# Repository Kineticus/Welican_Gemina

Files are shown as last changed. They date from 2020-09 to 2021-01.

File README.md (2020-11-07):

# Welican Gemina

A custom ESP32 module that controls WS2811 lights, a 1.3" OLED I2C, a MSGEQ7 Microphone board, and 2 encoders.

```
Your README file is normally the first entry point to your code. It should tell people why they should use your module, how they can install it, and how they can use it. Standardizing how you write your README makes creating and maintaining your READMEs easier. Great documentation takes work!
```

This repository contains:

1. [Board Design](BOARD_DESIGN.md) to show the custom ESP32 boarddesigned for this project.

## TODOs

- WIFI Manager
- ~~Saving Favorites~~
  - ~~Favorites Menu~~
- ~~Settings~~
  - ~~Set Led Count~~
  - ~~Show IP~~
  - Timeout (short, medium, long, extra long, never)
    - Show Weather/Clock
    - Turn off
  - ~~Clock Types~~
  - ~~Random Mode Speed (short, medium, long, extra long, never)~~
  - ~~Color Order (RGB, GRB, etc)~~
  - ~~Factory Reset (reset EPROM values to default, favorites, highscores)~~
- ~~Random Mode at beginning of categories~~
- ~~Fade between patterns (to prevent quick spins on pattern knob)~~
- Audio Input morphs Music Visualizer category lights
- More visualizers (VZ)
  - Random VZ for each category (at the beginning of category)
  - Differnt types of random (at the end of category)
- ~~Weather status~~
  - ~~By Zipcode~~
  - VZ based on weather
- ~~Get Time~~
  - ~~Show time in top menu~~

## Table of Contents

- [Background](#background)
- [Install](#install)
  - [Install Arduino Libraries](#install-arduino-libraries)
  - [VS Code & C++](#vs-code-&-c++)
- [Related Documents](#related-documents)
- [Maintainers](#maintainers)
- [Contributing](#contributing)
- [Helpful Links](#helpful-links)
- [FastLed Examples](#fastled-examples)
- [License](#license)

## Background
```
  // TODO add stuff
```
## Install

This project requires the [Arduino IDE](https://www.arduino.cc/en/Main/Software).

1. Install [Arduino IDE](https://www.arduino.cc/en/Main/Software).
2. In the Ardunio IDE, go to `File > Preferences` (CTRL + Comma).
    
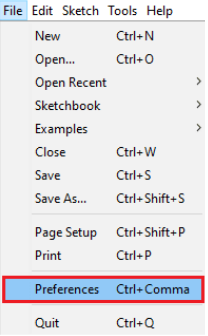
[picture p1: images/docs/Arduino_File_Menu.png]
Arudino File Menu
    

3. Enter `https://dl.espressif.com/dl/package_esp32_index.json` into the “Additional Board Manager URLs” field as shown in the figure below. Then, click the “OK” button.

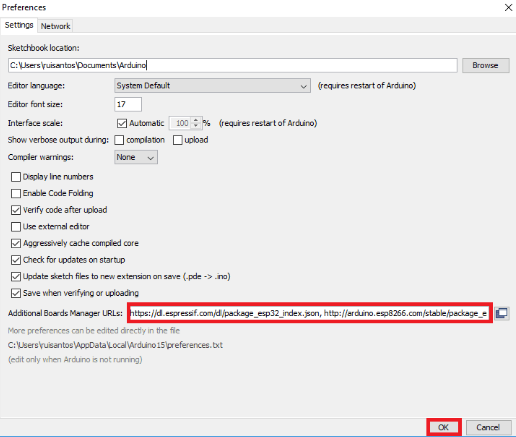
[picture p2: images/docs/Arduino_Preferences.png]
Arudino Preferneces
    

  - Note: if you already have the ESP8266 boards URL, you can separate the URLs with a comma as follows:
  `https://dl.espressif.com/dl/package_esp32_index.json, http://arduino.esp8266.com/stable/package_esp8266com_index.json`

4. Open the Boards Manager. Go to `Tools > Board > Boards Manager`

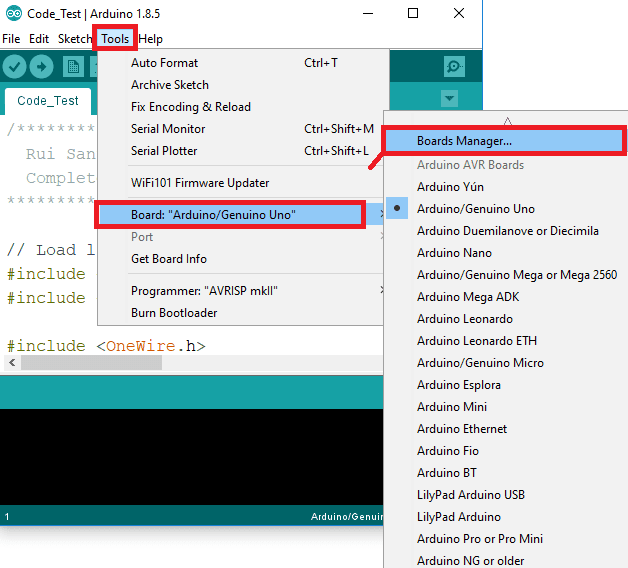
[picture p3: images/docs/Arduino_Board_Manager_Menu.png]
Arudino Board Manager Menu
    

5. Search for ESP32 and press install button for the “ESP32 by Espressif Systems“

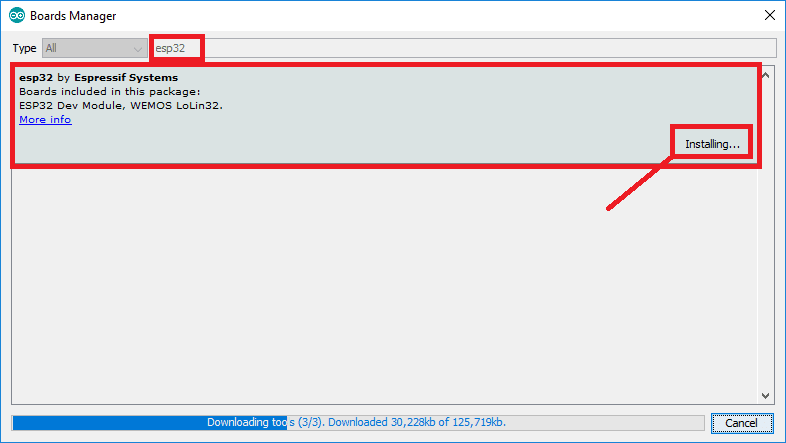
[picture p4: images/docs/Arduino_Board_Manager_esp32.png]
Arudino Board Manager Menu
    

    - That’s it! Make sure to change the Board under the Tools menu to “ESP32 Dev Module”

### Install Arduino Libraries

6. Libraries `Tools > Manage Libraries` (Location is User Directory\Documents\Arduino\libraries)
  - [ESP32Encoder](https://github.com/madhephaestus/ESP32Encoder)
  - [FastLED](https://github.com/FastLED/FastLED/wiki)
    - [FastLED Samguyer Fork](https://github.com/samguyer/FastLED) *Optional
  - [arduinoFFT](https://github.com/kosme/arduinoFFT)
  - [U8g2](https://github.com/olikraus/u8g2/wiki/u8g2reference)
  - [ESPAsyncWebServer](https://github.com/me-no-dev/ESPAsyncWebServer) *Must be installed manually
  - [ASyncTCP](https://github.com/me-no-dev/AsyncTCP) *Must be installed manually
  - [ESP32 File System Tool](https://github.com/me-no-dev/arduino-esp32fs-plugin) *Must be installed manually by copying to Tools folder!! Read instructions carefully.
  
### Create Wifi Credentials file

7. Create a file called `Secrets.h` in the main folder.
That file should include the following:
```
#define WIFI_SSID "your-wifi-ssid-goes-here"
#define WIFI_PASSWORD "your-wifi-password-goes-here"
#define OPEN_WEATHER_API_KEY "your-open-weather-api-key"
```

You will need to replace the strings with your WIFI SSID and PASSWORD

### VS Code & C++
  - [.vscode/c_app_properties.json](https://code.visualstudio.com/docs/cpp/customize-default-settings-cpp)
  - [Arduino Extension](https://marketplace.visualstudio.com/items?itemName=vsciot-vscode.vscode-arduino)
  - [C++ Extension](https://marketplace.visualstudio.com/items?itemName=ms-vscode.cpptools)
  - [GitLens Extension](https://marketplace.visualstudio.com/items?itemName=eamodio.gitlens)

## Related Documents

- [Welican Project Doc](https://docs.google.com/document/d/e/2PACX-1vS1qt4seWkiZLkJHX4LD_V3VYEt1su2fU610a7UOJ1a_LkRgppqzjMMRaHVzRj_jQmDRsJIRdGVeDGK/pub) - The brain-dump file created by @Kinectus
- [BOM](https://docs.google.com/spreadsheets/d/1Lj1XwBXrHm5YGtD2jA4sHXP_yh42TAKp-GVNhS_lHCg/edit?usp=sharing) - Price / Cost spreadsheet created by @Kinectus

## Maintainers

  - [@Kinectus](https://github.com/Kineticus/)

  - [@MaylorTaylor](https://github.com/MaylorTaylor/)

## Contributing

Feel free to dive in! [Open an issue](https://github.com/Kineticus/Welican_Gemina/issues/new) or submit PRs.

Standard Readme follows the [Contributor Covenant](http://contributor-covenant.org/version/1/3/0/) Code of Conduct.

## Helpful Links

  - [C++ Classes](https://www.stroustrup.com/C++11FAQ.html#member-init)
  - [Custom XBM Image Convert](https://www.online-utility.org/image/convert/to/XBM)
  - [Arduino C++ & VSCode](https://learn.sparkfun.com/tutorials/efficient-arduino-programming-with-arduino-cli-and-visual-studio-code/all)
  - [Arduino Intellisense VSCode](https://cuneyt.aliustaoglu.biz/en/enabling-arduino-intellisense-with-visual-studio-code/)
  - [Experimental FastLED RGBSet](https://github.com/FastLED/FastLED/wiki/RGBSet-Reference)
  - [Refactoring out DELAY](https://forum.arduino.cc/index.php?topic=537644.0)
  - [UG82 Screen Library](https://github.com/olikraus/u8g2)
  - [Strings for CPP](https://cpp4arduino.com/2018/11/21/eight-tips-to-use-the-string-class-efficiently.html)

## FastLED Examples

  - [Demos](https://github.com/atuline/FastLED-Demos)
  - [Demos 2](https://github.com/marmilicious/FastLED_examples)
  - [Demos 3](https://www.tweaking4all.com/hardware/arduino/adruino-led-strip-effects/)
  - [Flagpole](https://github.com/chemdoc77/CD77_FastLED_Projects/tree/master/CD77_Flagpole_Project)
  - [Chase Demo](https://github.com/chemdoc77/CD77_FastLED/tree/master/CD77_Chase_Demo)

## License

[MIT License](/LICENSE.md) © Welican LLC

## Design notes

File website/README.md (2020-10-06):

# Welican Gemina Website

## Installing

  1. Make sure you download [Node.JS](https://nodejs.org/en/download/) (so you can use `npm` commands)
  2. Make sure your terminal is in the `/website` folder.
  3. Run `npm install` to install all the dependencies in the `package.json` file.

## Build Process
  
  1. Run `npm run build`
    - This will use the `webpack.config.js` file to grab all files in `/images`, all `./styles/**.scss` files, and all the `./src/**.js` files and put the minified files into `./data/` folder.
  2. Go To ARUDINO SOFTWARE, then TOOLS > `ESP32 Data Sketch Upload`. Click this and do the "upload" to add the files to the ESP32 device.

## Developing

  1. Run `npm run start:dev`, this will launch a local server and host the files in the `./src` folder at `http://localhost:8080/`

## Helpful Places

  - [CSS from Mini.css](https://minicss.org/docs#getting-started)
  - [Images using ESP32](https://randomnerdtutorials.com/display-images-esp32-esp8266-web-server/)

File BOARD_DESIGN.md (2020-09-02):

# ESP32 Board Design

## Table of Contents

- [ESP Pictures](#esp-pictures)
- [Technical Information about ESP32](#Technical-Information-about-ESP32)
- [Advanced Troubleshooting and Programming](#Advanced-Troubleshooting-and-Programming)
- [Encoder](#encoders)
- [Display](#display)
- [LED Signaling](#LED-Signaling)
- [Case / Enclosure](#case-/-enclosure)

## ESP Pictures

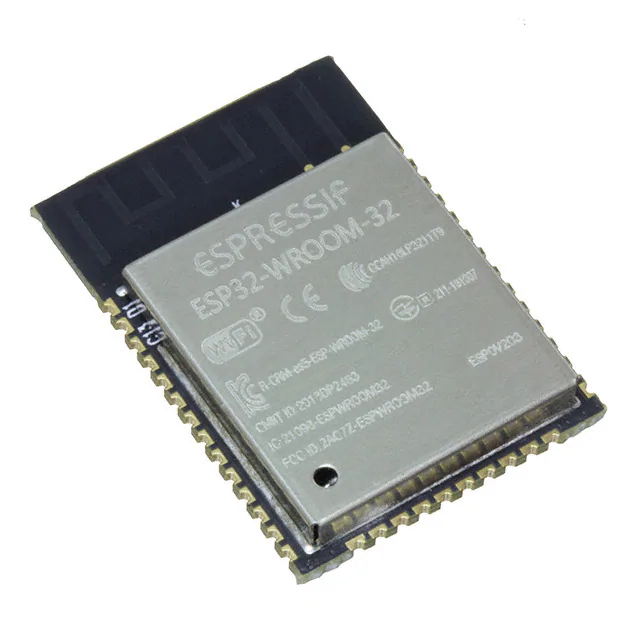
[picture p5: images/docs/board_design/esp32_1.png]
ESP32 1


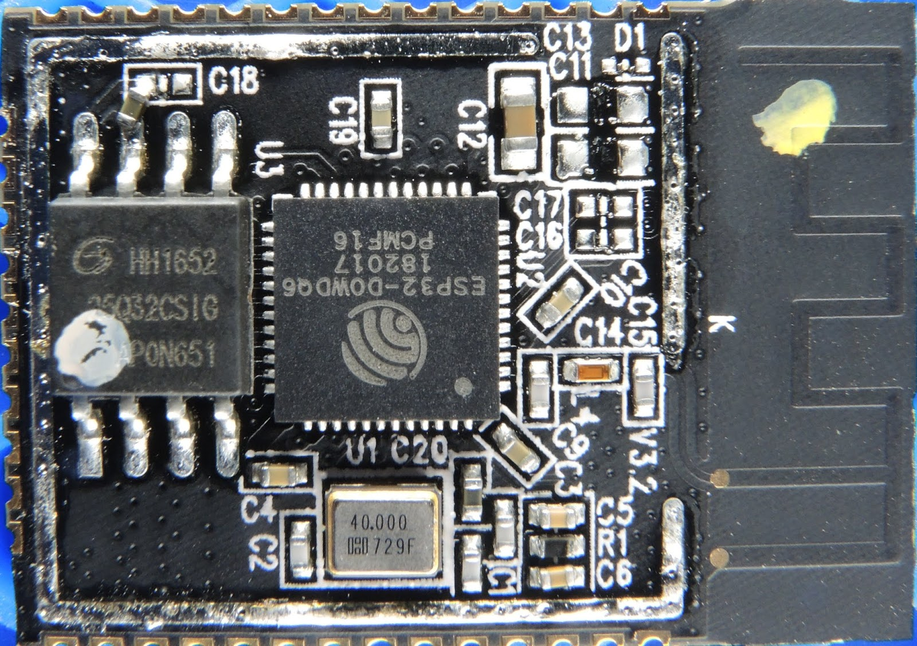
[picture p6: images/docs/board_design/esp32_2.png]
ESP32 2


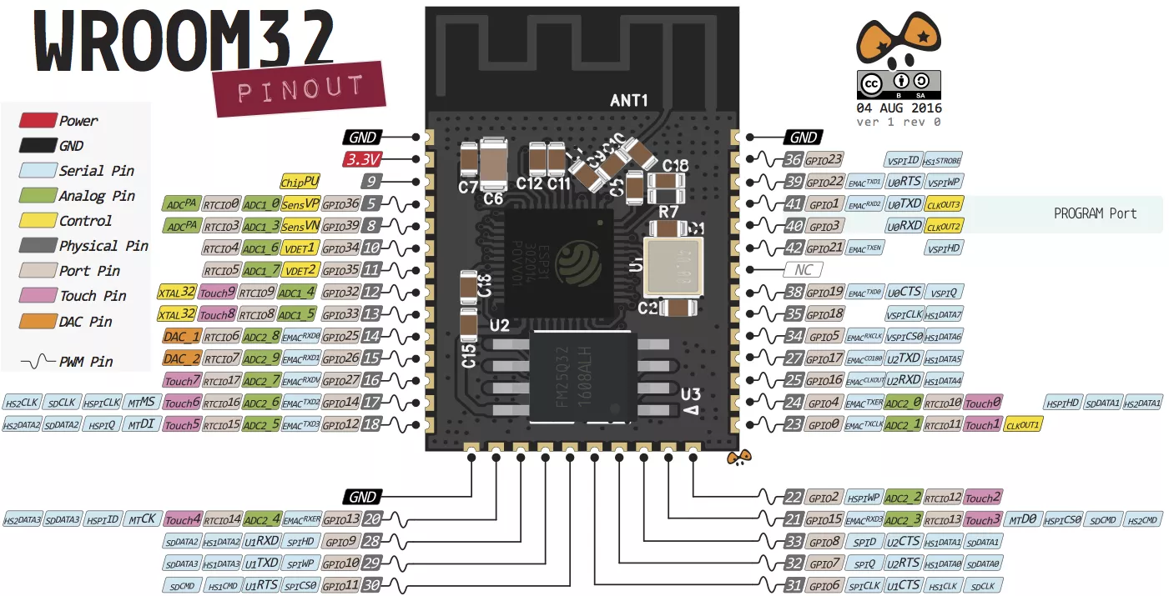
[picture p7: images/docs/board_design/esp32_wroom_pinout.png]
ESP32 Wroom PinOut


## Technical Information about ESP32

  - [Data Sheet](https://www.mouser.com/datasheet/2/891/esp32-wroom-32d_esp32-wroom-32u_datasheet_en-1365844.pdf)

  - [Strapping Pins and Boot Mode Selection](https://github.com/espressif/esptool/wiki/ESP32-Boot-Mode-Selection)

    - USB Serial Monitor - PuTTY on Serial Port at 115200 baud
      - This will report which boot mode is selected based on strapping Pins
  - [Multicore](https://randomnerdtutorials.com/esp32-dual-core-arduino-ide/)

  ## Advanced Troubleshooting and Programming       

  - [ESP Tool](https://github.com/espressif/esptool) (Requires Python)
    - Once Python is installed open an elevated command prompt and navigate to the extracted files
    - To get board information:
      - `py espefuse.py --port COM3 summary`
    - Flash Information:
      - `py esptool.py flash_id`
    - You’ll find you have missing packages. Use the structure below to install them
      - `python -m pip install pyserial`

## Encoders

  - [Encoder Library](https://www.pjrc.com/teensy/td_libs_Encoder.html)
    - This library is able to attach inputs to interrupt pins. This prevents constant polling.
  - Wiring / Pins

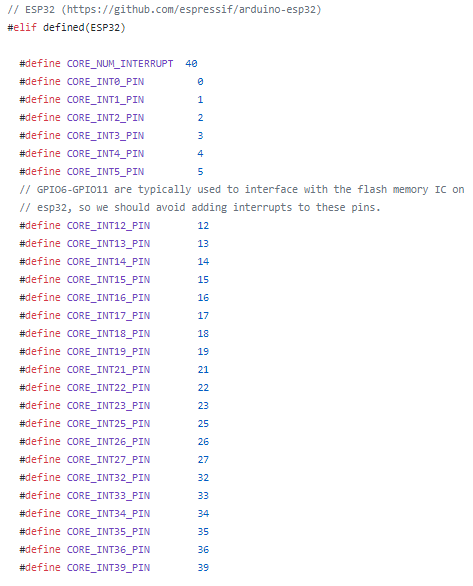
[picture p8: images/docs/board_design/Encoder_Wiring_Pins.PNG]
Encoder Wiring Pins
    

## Display

  - SSD1106 based OLED (128 x 64 pixels)

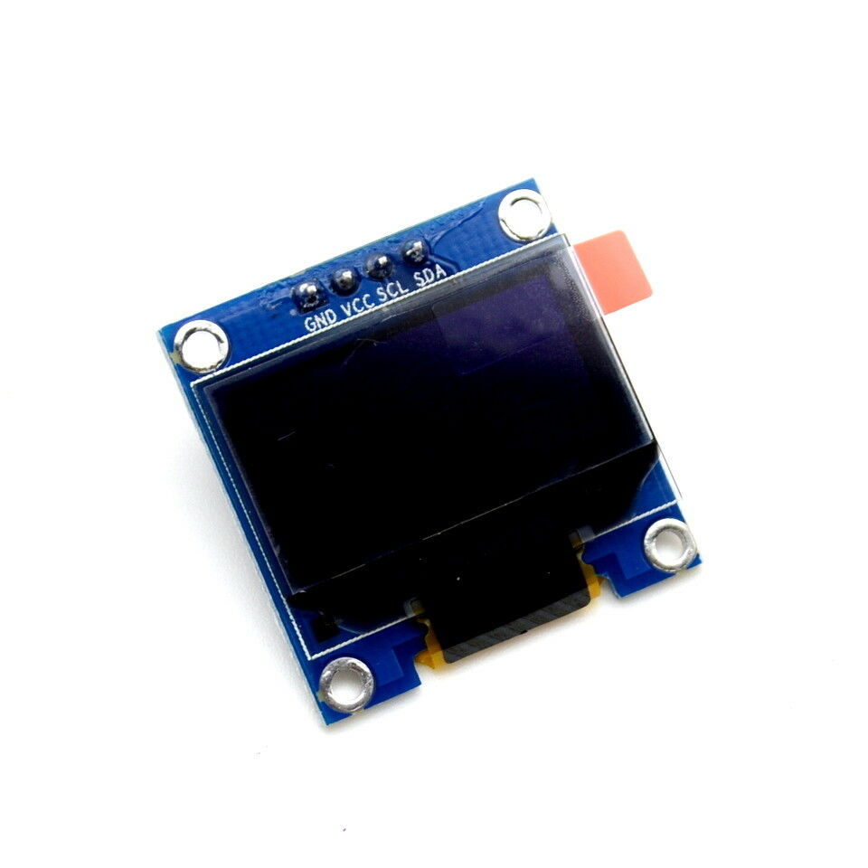
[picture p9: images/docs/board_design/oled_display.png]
OLED Display
    

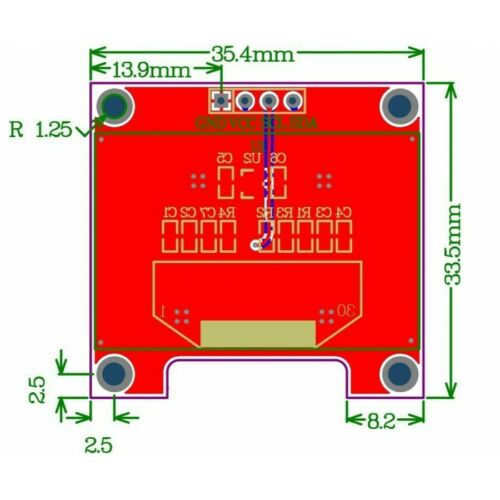
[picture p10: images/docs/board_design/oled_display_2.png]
OLED Display 2
    

    - Available in White or Blue
    - Library: [U8g2lib](https://github.com/olikraus/u8g2)
      - I2C address: 0x3C
      - #define OLED_RESET -1
    - Wiring / Pins
      - SCL   GPIO 22   (hardware I2C SCL)
      - SDA   GPIO 21   (hardware I2C SDA)

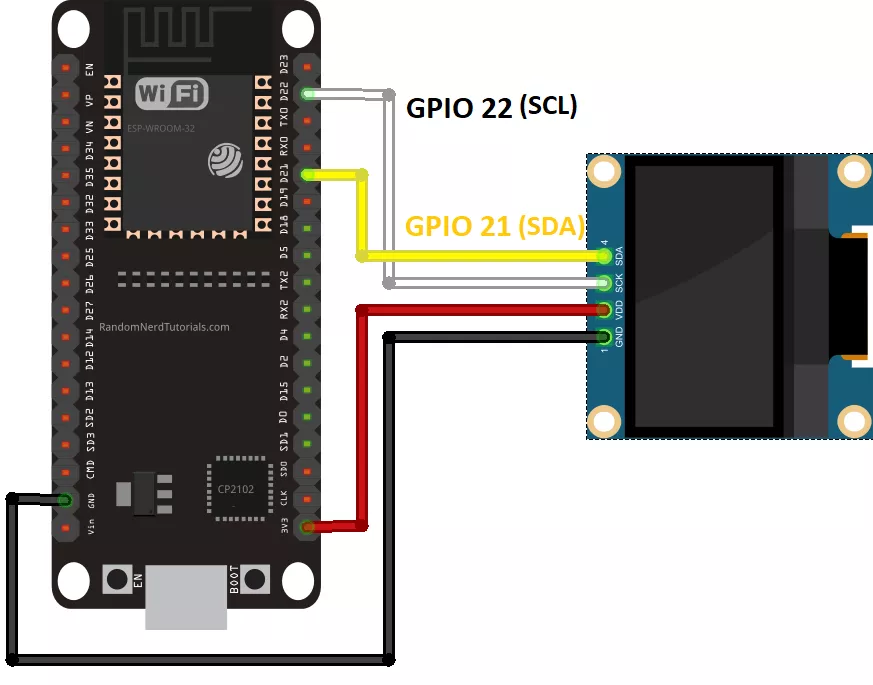
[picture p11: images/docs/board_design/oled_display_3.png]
OLED Display 3
    

    - Usage
      - [Custom Images](https://www.online-utility.org/image/convert/to/XBM)
      - [Custom Font](https://github.com/olikraus/u8g2/wiki/fntlistall)
      - [Custom Shapes / Drawing](https://github.com/olikraus/u8g2/wiki/u8g2reference)

## LED Signaling

  - [FastLED Library](https://github.com/FastLED/FastLED/)
    - [FastLED Wiki](https://github.com/FastLED/FastLED/wiki/Overview)
      - [Controlling LEDS](https://github.com/FastLED/FastLED/wiki/Controlling-leds)
      - [Pixel Reference](https://github.com/FastLED/FastLED/wiki/Pixel-reference)
      - [HSV Colors](https://github.com/FastLED/FastLED/wiki/FastLED-HSV-Colors)
      - [Gradient Color Palettes](https://github.com/FastLED/FastLED/wiki/Gradient-color-palettes)
    - Technical
      - [Clockless RMT ESP32](https://github.com/FastLED/FastLED/blob/master/platforms/esp/32/clockless_rmt_esp32.h)
      - [Temporal Dithering](https://github.com/FastLED/FastLED/wiki/FastLED-Temporal-Dithering)
      - [High Performance Math](https://github.com/FastLED/FastLED/wiki/High-performance-math)
      - [Experimental Hardware SPI](https://github.com/FastLED/FastLED/pull/1047)
  - Wiring / Pins for RMT Hardware Accelerated use on ESP32. Allows up to 8 unique strands.
    - [Fast Pin ESP32](https://github.com/FastLED/FastLED/blob/master/platforms/esp/32/fastpin_esp32.h)

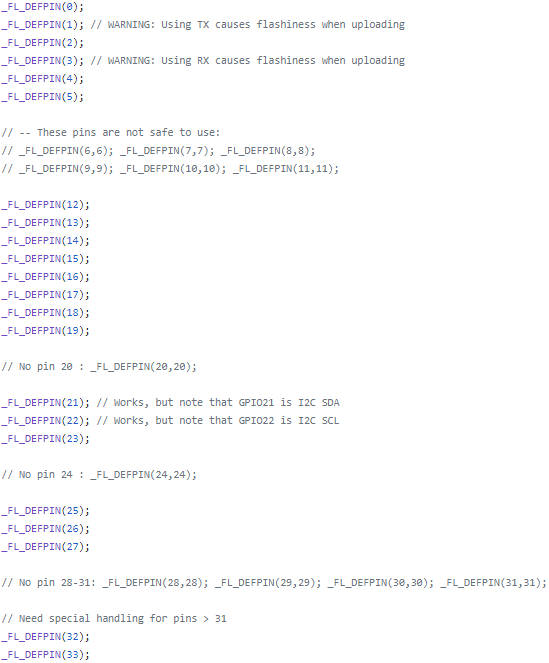
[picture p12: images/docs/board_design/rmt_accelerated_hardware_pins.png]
Wiring / Pins for RMT Hardware Accelerated use on ESP32
    

## Case / Enclosure

  - [ABS Plastic boxes with board standoffs](https://www.hammfg.com/electronics/small-case/plastic/1591xx)
  - [Polycarbonate Plastic boxes without board standoffs](https://www.hammfg.com/electronics/small-case/plastic/1591t)
  - [Sloping Console](https://www.hammfg.com/electronics/small-case/plastic/1599t)
  - [Anti-slip Feet 3M SJ5001](https://www.mouser.com/ProductDetail/3m/sj5001-blk/?qs=ItEYEd4DnG1l70qV%252buXsng%3D%3D)
  - [Stand-Offs / Screws for OLED/PCB]()
  - 3D Printed Custom Box
    - Sam will design and print.  Can utilize online printer shops for bulk manufacturing.

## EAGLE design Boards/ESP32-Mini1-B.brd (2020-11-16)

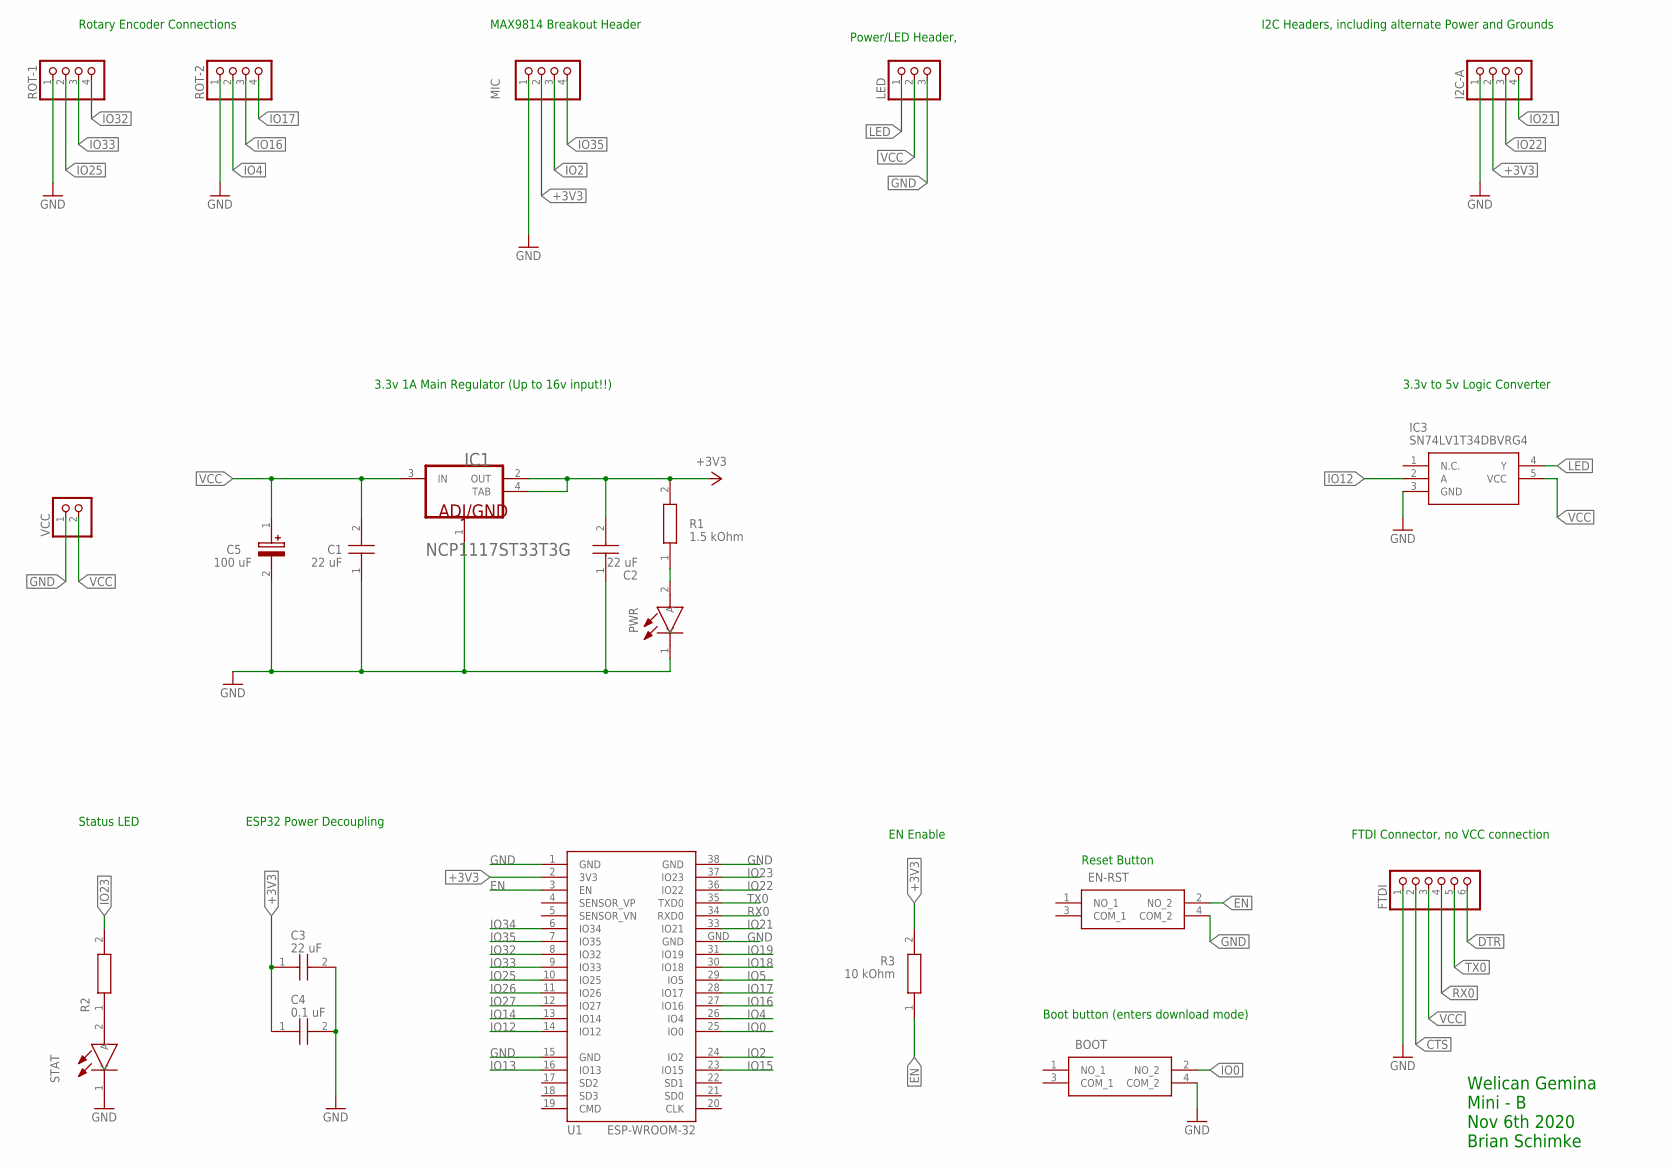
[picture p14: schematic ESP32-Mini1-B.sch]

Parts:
BOOT: PTS647SK70SMTR2LFS
C1, C2, C3: 22 uF; CAPC3216X180N
C4: 0.1 uF; CAPC3216X180N
C5: 100 uF; CAPAE660X770N
EN-RST: PTS647SK70SMTR2LFS
FTDI: PINHD-1X6; 1X06
I2C-A: PINHD-1X4; 1X04
IC1: ON_SEMICONDUCTOR_NCP1117ST33T3GON_SEMICONDUCTOR_N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; ON_SEMICONDUCTOR_NCP1117ST33T3G_0
IC3: SN74LV1T34DBVRG4; SOT95P280X145-5N
LED: PINHD-1X3; 1X03
MIC: PINHD-1X4; 1X04
PWR: 150120AS75000; LEDSC320X160X78-2N
R1: 1.5 kOhm; RESC3216X60N
R2: CRCW12061K00FKEB; RESC3216X60N
R3: 10 kOhm; RESC3216X60N
ROT-1, ROT-2: PINHD-1X4; 1X04
STAT: 150120AS75000; LEDSC320X160X78-2N
U1: ESP-WROOM-32
VCC: PINHD-1X2; 1X02

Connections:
+3V3: C2.2, C3.1, C4.1, I2C-A.2, IC1.2 (OUT), IC1.4 (TAB), MIC.2, R1.2, R3.2, U1.2 (3V3)
CTS: FTDI.2
DTR: FTDI.6
EN: EN-RST.2 (NO_2), R3.1, U1.3 (EN)
GND: BOOT.4 (COM_2), C1.1, C2.1, C3.2, C4.2, C5.2 (-), EN-RST.4 (COM_2), FTDI.1, I2C-A.1, IC1.1 (ADJ/GND), IC3.3 (GND), LED.3, MIC.1, PWR.1 (K), ROT-1.1, ROT-2.1, STAT.1 (K), U1.1 (GND), U1.15 (GND), U1.38 (GND), U1.GND, VCC.1
IO0: BOOT.2 (NO_2), U1.25 (IO0)
IO2: MIC.3, U1.24 (IO2)
IO4: ROT-2.2, U1.26 (IO4)
IO5: U1.29 (IO5)
IO12: IC3.2 (A), U1.14 (IO12)
IO13: U1.16 (IO13)
IO14: U1.13 (IO14)
IO15: U1.23 (IO15)
IO16: ROT-2.3, U1.27 (IO16)
IO17: ROT-2.4, U1.28 (IO17)
IO18: U1.30 (IO18)
IO19: U1.31 (IO19)
IO21: I2C-A.4, U1.33 (IO21)
IO22: I2C-A.3, U1.36 (IO22)
IO23: R2.2, U1.37 (IO23)
IO25: ROT-1.2, U1.10 (IO25)
IO26: U1.11 (IO26)
IO27: U1.12 (IO27)
IO32: ROT-1.4, U1.8 (IO32)
IO33: ROT-1.3, U1.9 (IO33)
IO34: U1.6 (IO34)
IO35: MIC.4, U1.7 (IO35)
LED: IC3.4 (Y), LED.1
unnamed: PWR.2 (A), R1.1
unnamed: R2.1, STAT.2 (A)
RX0: FTDI.4, U1.34 (RXD0)
TX0: FTDI.5, U1.35 (TXD0)
VCC: C1.2, C5.1 (+), FTDI.3, IC1.3 (IN), IC3.5 (VCC), LED.2, VCC.2

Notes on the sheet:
ESP32 Power Decoupling
EN Enable
3.3v to 5v Logic Converter
Reset Button
Boot button (enters download mode)
3.3v 1A Main Regulator (Up to 16v input!!)
Status LED
FTDI Connector, no VCC connection
Rotary Encoder Connections
I2C Headers, including alternate Power and Grounds
Power/LED Header,
MAX9814 Breakout Header
Welican Gemina Mini - B Nov 6th 2020 Brian Schimke

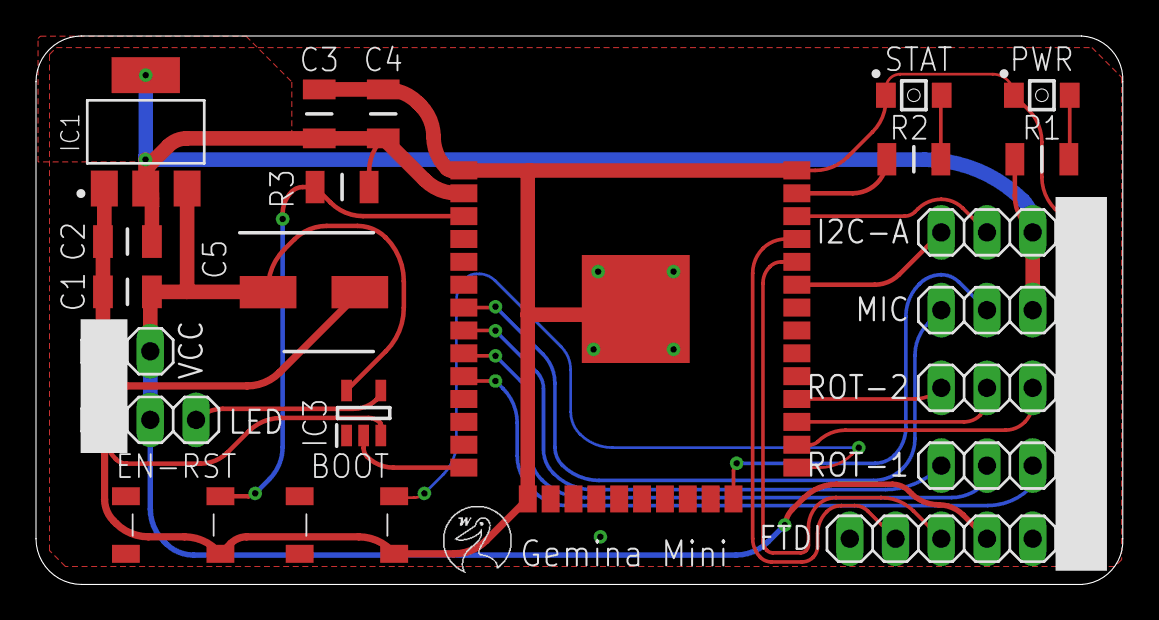
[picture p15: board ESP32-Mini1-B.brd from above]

Board: 2 copper layers, 60.4 x 30.5 mm, 22 parts (0 on the bottom side), 22 nets.

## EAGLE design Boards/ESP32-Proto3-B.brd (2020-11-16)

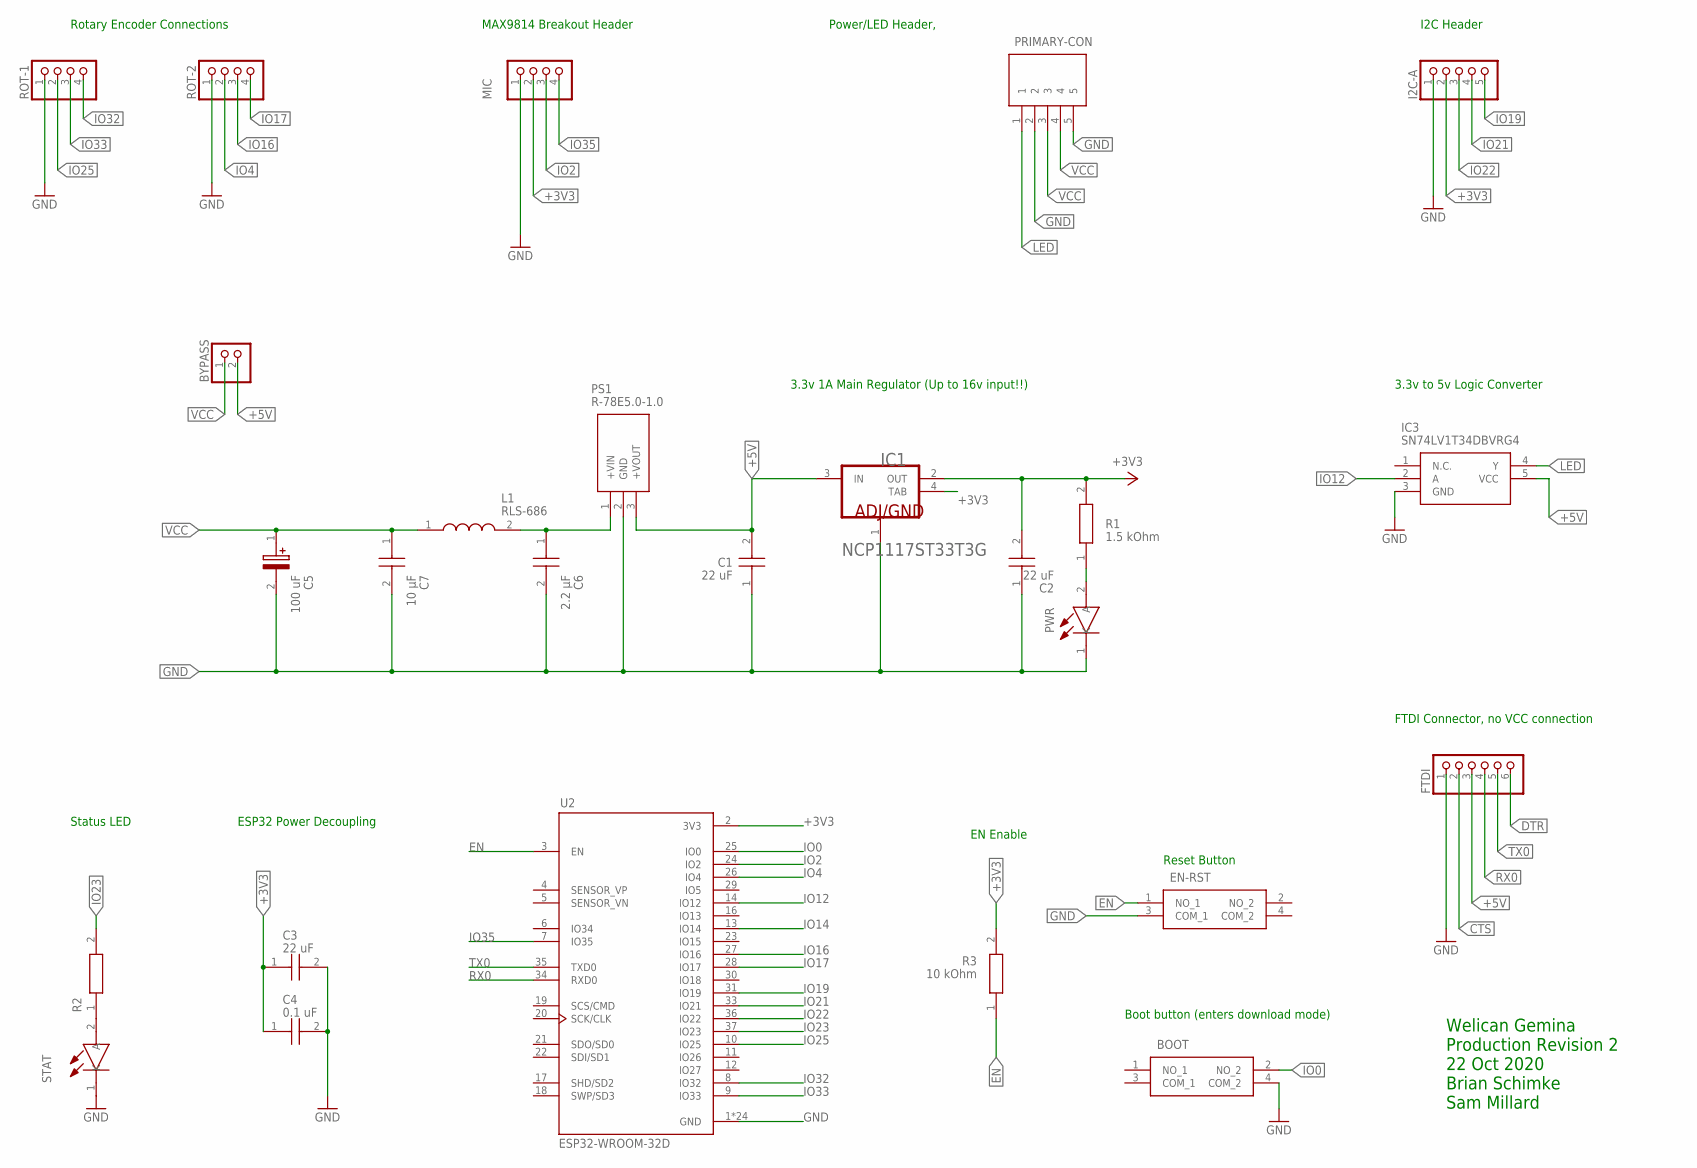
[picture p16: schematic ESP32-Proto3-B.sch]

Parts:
BOOT: PTS647SK70SMTR2LFS
BYPASS: PINHD-1X2; 1X02
C1, C2, C3: 22 uF; CAPC3216X180N
C4: 0.1 uF; CAPC3216X180N
C5: 100 uF; CAPAE660X770N
C6: 2.2 μF; CAPC3216X180N
C7: 10 μF; CAPC3216X180N
EN-RST: PTS647SK70SMTR2LFS
FTDI: PINHD-1X6; 1X06
I2C-A: PINHD-1X5; 1X05
IC1: ON_SEMICONDUCTOR_NCP1117ST33T3GON_SEMICONDUCTOR_N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; ON_SEMICONDUCTOR_NCP1117ST33T3G_0
IC3: SN74LV1T34DBVRG4; SOT95P280X145-5N
L1: RLS-686; RLS686
MIC: PINHD-1X4; 1X04
PRIMARY-CON: 1984646
PS1: R-78E5.0-1.0; R78E5010
PWR: 150120AS75000; LEDSC320X160X78-2N
R1: 1.5 kOhm; RESC3216X60N
R2: CRCW12061K00FKEB; RESC3216X60N
R3: 10 kOhm; RESC3216X60N
ROT-1, ROT-2: PINHD-1X4; 1X04
STAT: 150120AS75000; LEDSC320X160X78-2N
U2: ESP32-WROOM-32D; MODULE_ESP32-WROOM-32D

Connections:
+3V3: C2.2, C3.1, C4.1, I2C-A.2, IC1.2 (OUT), IC1.4 (TAB), MIC.2, R1.2, R3.2, U2.2 (3V3)
+5V: BYPASS.2, C1.2, FTDI.3, IC1.3 (IN), IC3.5 (VCC), PS1.3 (+VOUT)
CTS: FTDI.2
DTR: FTDI.6
EN: EN-RST.1 (NO_1), R3.1, U2.3 (EN)
GND: BOOT.4 (COM_2), C1.1, C2.1, C3.2, C4.2, C5.2 (-), C6.2, C7.2, EN-RST.3 (COM_1), FTDI.1, I2C-A.1, IC1.1 (ADJ/GND), IC3.3 (GND), MIC.1, PRIMARY-CON.2, PRIMARY-CON.5, PS1.2 (GND), PWR.1 (K), ROT-1.1, ROT-2.1, STAT.1 (K), U2.1 (GND), U2.15 (GND), U2.38 (GND), U2.39_1 (GND), U2.39_2 (GND), U2.39_3 (GND), U2.39_4 (GND), U2.39_5 (GND), U2.39_6 (GND), U2.39_7 (GND), U2.39_8 (GND), U2.39_9 (GND), U2.39_10 (GND), U2.39_11 (GND), U2.39_12 (GND), U2.39_13 (GND), U2.39_14 (GND), U2.39_15 (GND), U2.39_16 (GND), U2.39_17 (GND), U2.39_18 (GND), U2.39_19 (GND), U2.39_20 (GND), U2.39_21 (GND)
IO0: BOOT.2 (NO_2), U2.25 (IO0)
IO2: MIC.3, U2.24 (IO2)
IO4: ROT-2.2, U2.26 (IO4)
IO12: IC3.2 (A), U2.14 (IO12)
IO14: U2.13 (IO14)
IO16: ROT-2.3, U2.27 (IO16)
IO17: ROT-2.4, U2.28 (IO17)
IO19: I2C-A.5, U2.31 (IO19)
IO21: I2C-A.4, U2.33 (IO21)
IO22: I2C-A.3, U2.36 (IO22)
IO23: R2.2, U2.37 (IO23)
IO25: ROT-1.2, U2.10 (IO25)
IO32: ROT-1.4, U2.8 (IO32)
IO33: ROT-1.3, U2.9 (IO33)
IO35: MIC.4, U2.7 (IO35)
LED: IC3.4 (Y), PRIMARY-CON.1
unnamed: PWR.2 (A), R1.1
unnamed: R2.1, STAT.2 (A)
RX0: FTDI.4, U2.34 (RXD0)
TX0: FTDI.5, U2.35 (TXD0)
VCC: BYPASS.1, C5.1 (+), C7.1, L1.1, PRIMARY-CON.3, PRIMARY-CON.4
VIN: C6.1, L1.2, PS1.1 (+VIN)

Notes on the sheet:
ESP32 Power Decoupling
EN Enable
3.3v to 5v Logic Converter
Reset Button
Boot button (enters download mode)
3.3v 1A Main Regulator (Up to 16v input!!)
Status LED
FTDI Connector, no VCC connection
Rotary Encoder Connections
I2C Header
Power/LED Header,
MAX9814 Breakout Header
Welican Gemina Production Revision 2 22 Oct 2020 Brian Schimke Sam Millard

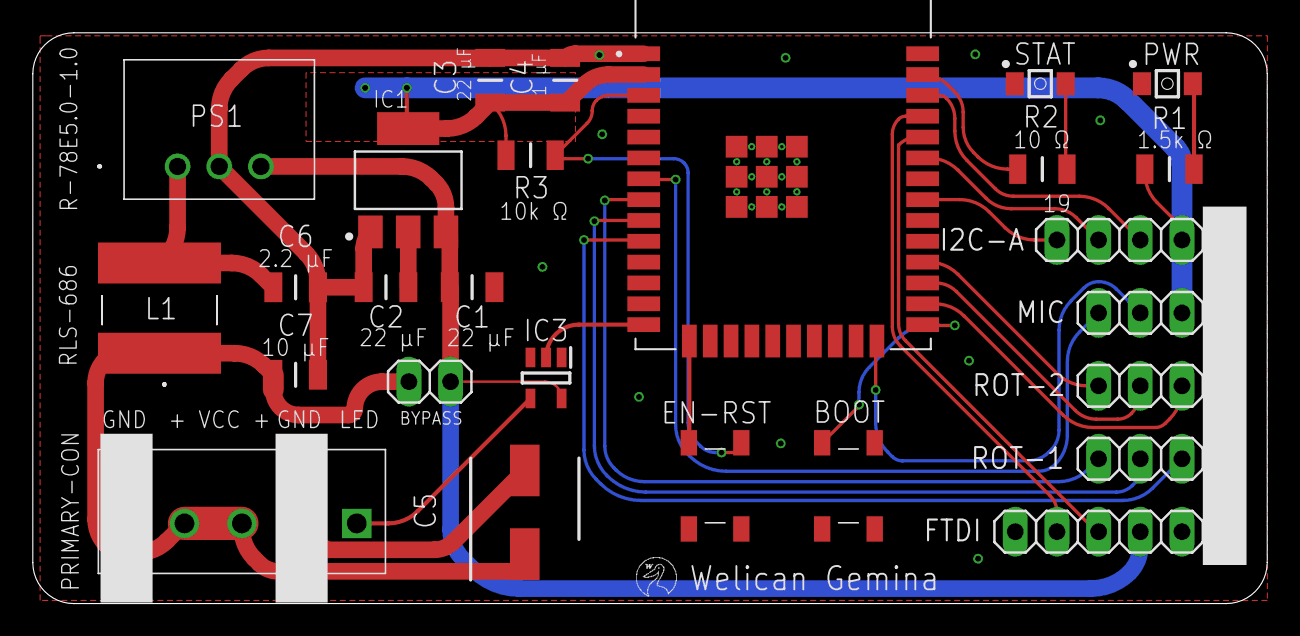
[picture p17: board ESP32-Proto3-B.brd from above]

Board: 2 copper layers, 75.2 x 34.8 mm, 26 parts (0 on the bottom side), 25 nets.

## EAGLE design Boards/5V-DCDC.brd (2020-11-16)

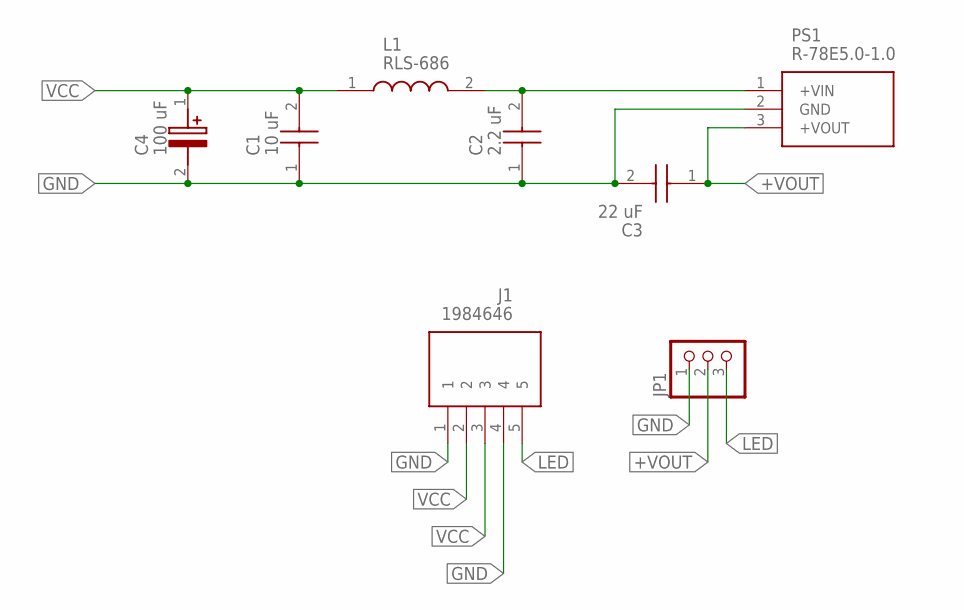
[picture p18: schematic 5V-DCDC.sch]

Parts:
C1: 10 uF; CAPC3216X180N
C2: 2.2 uF; CAPC3216X180N
C3: 22 uF; CAPC3216X180N
C4: 100 uF; CAPAE660X770N
J1: 1984646
JP1: PINHD-1X3; 1X03
L1: RLS-686; RLS686
PS1: R-78E5.0-1.0; R78E5010

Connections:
+VIN: C2.2, L1.2, PS1.1 (+VIN)
+VOUT: C3.1, JP1.2, PS1.3 (+VOUT)
GND: C1.1, C2.1, C3.2, C4.2 (-), J1.1, J1.4, JP1.1, PS1.2 (GND)
LED: J1.5, JP1.3
VCC: C1.2, C4.1 (+), J1.2, J1.3, L1.1

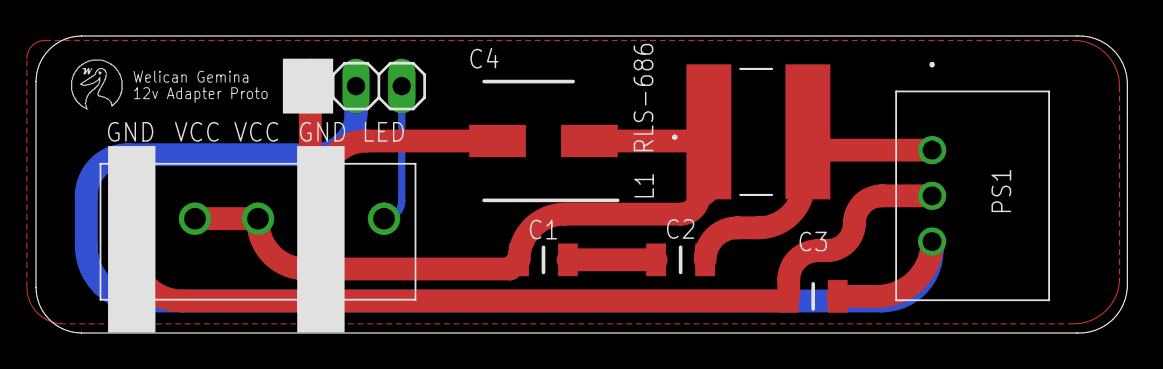
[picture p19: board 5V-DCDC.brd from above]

Board: 2 copper layers, 60.6 x 16.5 mm, 8 parts (0 on the bottom side), 5 nets.

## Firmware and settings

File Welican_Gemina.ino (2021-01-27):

/**************************************************************************
 *
 * Collaborative Project for a Next Generation WS LED Control Box
 *
 * Beta Version
 *
 * August 2020
 *
 * Brian Schimke (brs0906@gmail.com)
 * Matt Taylor (maylortaylor@gmail.com)
 *
 *************************************************************************
*/

// ----------------------------------------------------------------
// INCLUDEs
// ----------------------------------------------------------------

#include <arduino.h>
#include <FastLED.h>
#include "images.h"
#include "EEPROM.h"
#include <Wire.h>
#include <U8g2lib.h>
#include <ESP32Encoder.h>
#include <WiFi.h>
#include <HTTPClient.h>
#include <DNSServer.h>
#include <Arduino_JSON.h>
#include "ESPAsyncWebServer.h"
#include "SPIFFS.h"
#include "time.h"
#include "Secrets.h"
#include <arduinoFFT.h>
#include "FirebaseESP32.h"
//#include <rom/rtc.h>

FASTLED_USING_NAMESPACE

// ----------------------------------------------------------------
// DEFINEs
// ----------------------------------------------------------------

#if defined(FASTLED_VERSION) && (FASTLED_VERSION < 3001000)
#warning "Requires FastLED 3.1 or later; check github for latest code."
#endif
#define VERSION_INFO "Beta 1.0 - 12/18/20"
#define KNOB_1C 25 //Program
#define KNOB_2C 4  //Brightness 14
#define MAX_MODES 9
#define SAMPLES 512         // Must be a power of 2. FAST 256 (40fps), NORMAL 512 (20fps), ACCURATE 1024 (10fps)
#define SAMPLING_FREQ 40000 // Hz, must be 40000 or less due to ADC conversion time. Determines maximum frequency that can be analysed by the FFT Fmax=sampleF/2.
#define AMPLITUDE 3000      // Depending on your audio source level, you may need to alter this value. Can be used as a 'sensitivity' control.
#define AUDIO_IN_PIN 35     // Signal in on this pin
#define NUM_BANDS 4         // To change this, you will need to change the bunch of if statements describing the mapping from bins to bands
#define NOISE 500           // Used as a crude noise filter, values below this are ignored
#define TOP 32
#define FRAMES_PER_SECOND 120
#define SCREEN_WIDTH 127
#define SCREEN_WIDTH_HALF 63
#define SCREEN_HEIGHT 63
#define SCREEN_HEIGHT_HALF 31
#define MAX_STARS 32
#define QSUBD(x, b) ((x > b) ? b : 0)     // Digital unsigned subtraction macro. if result <0, then => 0. Otherwise, take on fixed value.
#define QSUBA(x, b) ((x > b) ? x - b : 0) // Analog Unsigned subtraction macro. if result <0, then => 0
#define DATA_PIN 18
#define DATA_PIN_A 12
#define LED_TYPE WS2811
#define COLOR_ORDER RGB
#define MAX_LEDS 512
int NUM_LEDS = 200;
#define LEDS_FOR_SIMPLEX 6
#define VISUALIZER_X 48
#define VISUALIZER_Y 128
#define STATUS_LED 0
// COOLING: How much does the air cool as it rises?
// Less cooling = taller flames.  More cooling = shorter flames.
// Default 50, suggested range 20-100
#define COOLING 90
// SPARKING: What chance (out of 255) is there that a new spark will be lit?
// Higher chance = more roaring fire.  Lower chance = more flickery fire.
// Default 120, suggested range 50-200.
#define SPARKING 50

// ----------------------------------------------------------------
// GLOBALs
// ----------------------------------------------------------------
FirebaseData firebaseData;
AsyncWebServer server(80);
DNSServer dnsServer; // Used for Captive Portal

class CaptiveRequestHandler : public AsyncWebHandler
{
public:
  CaptiveRequestHandler() {}
  virtual ~CaptiveRequestHandler() {}

  bool canHandle(AsyncWebServerRequest *request)
  {
    //request->addInterestingHeader("ANY");
    return true;
  }

  void handleRequest(AsyncWebServerRequest *request)
  {
    AsyncResponseStream *response = request->beginResponseStream("text/html");
    response->print("<!DOCTYPE html><html><head><title>Captive Portal</title></head><body>");
    response->print("<p>This is out captive portal front page.</p>");
    response->printf("<p>You were trying to reach: http://%s%s</p>", request->host().c_str(), request->url().c_str());
    response->printf("<p>Try opening <a href='http://%s'>this link</a> instead</p>", WiFi.softAPIP().toString().c_str());
    response->print("</body></html>");
    request->send(response);
  }
};

TaskHandle_t inputComputeTask = NULL;

//0.96" OLED
//U8G2_SSD1306_128X64_NONAME_F_HW_I2C u8g2(U8G2_R0, /* reset=*/ U8X8_PIN_NONE);

//1.3" OLED, small glitch on 2.4"
U8G2_SH1106_128X64_NONAME_F_HW_I2C u8g2(U8G2_R0, /* reset=*/ 5);

//2.4" OLED, ORIGINAL BOARDS, small glitch on 1.3"
// U8G2_SSD1309_128X64_NONAME0_F_HW_I2C u8g2(U8G2_R0, /* reset=*/ 5);

//2.4" OLED, MODERN BOARDS, small glitch on 1.3"
//U8G2_SSD1309_128X64_NONAME0_F_HW_I2C u8g2(U8G2_R0, /* reset=*/19);

/*
For EST - UTC -5.00 : -5 * 60 * 60 : -18000
For EDT - UTC -4.00 : -4 * 60 * 60 : -14400
For UTC +0.00 : 0 * 60 * 60 : 0
*/
struct tm timeinfo;
int T[] = {0x15, 0x38, 0x32, 0x2c, 0x0d, 0x13, 0x07, 0x2a};
static float onethird = 0.333333333;
static float onesixth = 0.166666667;

// ----------------------------------------------------------------
// STRUCTs
// ----------------------------------------------------------------
struct Globals
{
  int temp[3];
  int timeZone;
  String timeZoneOffset;
  String timeZoneName;
  int tempValue;
  int currentSpeed;
  unsigned long newTime;
  unsigned int samplingPeriodUs;
  int runMode;
  int mode;
  int modeMax;
  int randomInterval;
  int randomMin;
  int randomMax;
  unsigned long randomTime;
  int randomMode;
  String ipAddress;
  String openWeatherMapApiKey;
  String ssid;
  String password;
  unsigned long networkReconnect;
  int networkTries;
  int networkScan;
  int signalStrength;
  int softAPEnable;
  const char *ntpServer;
  int animationFrame;

  ESP32Encoder encoder;
  ESP32Encoder encoder2;
  CRGB clr1;
  CRGB clr2;
  double vReal[SAMPLES];
  double vImag[SAMPLES];
};
Globals globals = {
    .temp = {},
    .timeZone = -5,
    .timeZoneOffset = "-18000",
    .timeZoneName = "",
    .tempValue = 0,
    .currentSpeed = 10,
    .newTime = 0,
    .samplingPeriodUs = 0,
    .runMode = 0,
    .mode = 0,
    .modeMax = MAX_MODES,
    .randomInterval = 0,
    .randomMin = 60000,
    .randomMax = 240000,
    .randomTime = 0,
    .randomMode = 0,
    .ipAddress = "",
    .openWeatherMapApiKey = OPEN_WEATHER_API_KEY,
    .ssid = WIFI_SSID,
    .password = WIFI_PASSWORD,
    .networkReconnect = 0,
    .networkTries = 0,
    .networkScan = 0,
    .signalStrength = 0,
    .softAPEnable = 0,
    .ntpServer = "pool.ntp.org",
    .animationFrame = 0};
arduinoFFT FFT = arduinoFFT(globals.vReal, globals.vImag, SAMPLES, SAMPLING_FREQ);

struct DevEnvironment
{
  int fps;   //dev, speed tracking for main loop
  int fftps; //dev, speed tracking for fft task
  int breathing;
};
DevEnvironment devEnv = {
    .fps = 0,
    .fftps = 0,
    .breathing = 1};

struct GlobalStrings
{
  String categoryName;
  String functionName;
  char categoryNameOutString[20];
  char functionNameOutString[20];
};
GlobalStrings globalStrings = {
    .categoryName = "",
    .functionName = "",
    .categoryNameOutString = {},
    .functionNameOutString = {}};

struct GlobalUser
{
  bool exists;
  String id;
  String name;
  String wifiName;
  int timezone;
  String zipcode;
  int highscore_snake;
  int highscore_snake2;
  int highscore_fallios;
  int highscore_brickBreaker;
  int timerDelay;
  int updateInitial;
  int updateInterval;
};
GlobalUser globalUser = {
    .exists = false,
    .id = "",
    .name = "",
    .wifiName = "",
    .timezone = 9999,
    .zipcode = "",
    .highscore_snake = 0,
    .highscore_snake2 = 0,
    .highscore_fallios = 0,
    .highscore_brickBreaker = 0,
    .timerDelay = 0,
    .updateInitial = 30000, // 30 seconds after boot
    .updateInterval = 15000 // every 15 after that
    };

struct GlobalTime
{
  int currentMinute;
  int currentHour;
  int currentDay;
  int currentDate;
  int currentMonth;
  bool currentPM;
  unsigned long startMillis;
  unsigned long currentMillis;
  const unsigned long period;
  int save;
  int timeOut;
  int currentDisplay;
  unsigned long currentDisplayTime;
  int timeDisplay1;
  int timeDisplay2;
  int timeDisplay3;
  unsigned long touchTime;
};
GlobalTime globalTime = {
    .currentMinute = 0,
    .currentHour = 100,
    .currentDay = 5,
    .currentDate = 1,
    .currentMonth = 0,
    .currentPM = 0,
    .startMillis = 0,
    .currentMillis = 0,
    .period = 1000,
    .save = 0,
    .timeOut = 30000,
    .currentDisplay = 0,
    .currentDisplayTime = 0,
    .timeDisplay1 = 0,
    .timeDisplay2 = 0,
    .timeDisplay3 = 0,
    .touchTime = 0};

struct GlobalUtils
{
  int encoderUnstick;
};
GlobalUtils utils = {
    .encoderUnstick = 0};

struct GlobalLED
{
  int pixelNumber;
  int interfade; //set this to 0 to disable fade in on boot. Set to 25 for fade in.
  int interfadeMax;
  int interfadeSpeed;
  int fadeDirection;      // 1 or 0, positive or negative
  int fadeDirection2;     // 1 or 0, positive or negative
  int fadeDirectionHTemp; // 1 or 0, positive or negative
  byte colorOrder;
  bool clearLEDS;
};
GlobalLED globalLED = {
    .pixelNumber = 0,
    .interfade = 18,
    .interfadeMax = 18,
    .interfadeSpeed = 14,
    .fadeDirection = 0,
    .fadeDirection2 = 0,
    .fadeDirectionHTemp = 0,
    .colorOrder = 0,
    .clearLEDS = false};

struct SimplexNoiseModel
{
  int nodeSpacing;
  int A[3];
  float hTemp;
  float timeInc;
  float spaceInc;
  float yoffset;
  float yoffsetMax;
  float xoffset;
  float ledArrayRed[MAX_LEDS + 1];
  float ledArrayGreen[MAX_LEDS + 1];
  float ledArrayBlue[MAX_LEDS + 1];
  float u;
  float v;
  float w;
  float s;
  float h;
  int g;
  int j;
  int k;
};
SimplexNoiseModel simplexNoise = {
    .nodeSpacing = (MAX_LEDS / LEDS_FOR_SIMPLEX),
    .A = {0, 0, 0},
    .hTemp = .420,
    .timeInc = 0.0025,
    .spaceInc = 0.05,
    .yoffset = 0.0,
    .yoffsetMax = 15000,
    .xoffset = 0.0};

struct PatternSettings
{
  int pattern[MAX_MODES + 1];
  byte patternAdjust[MAX_MODES + 1][100];
  int favoritePattern[50]; //all are used under the hood
  int favoritePatternAdjust[50];
  int favoriteMode[50];  //declare memory for all 50 favorites
  int numberOfFavorites; //Max 50, loads all 50 at program load, dynamically assignable
  int tempPattern;
  int currentPattern;
  int displayPattern;
  int randomPattern;
  uint8_t gHue;           // rotating "base color" used by many of the patterns
  int8_t flowDirection;   // Use either 1 or -1 to set flow direction
  bool gReverseDirection; //false = center outward, true = from ends inward
  bool sizeUpdate;
  bool moving;
  uint8_t speed;
  bool fadingTail;  // Add fading tail?
  uint8_t fadeRate; // How fast to fade out tail. [0-255]
  float valueMax;   // Pulse maximum value (Should be larger then valueMin).
  float valueMin;   // Pulse minimum value (Should be less then valueMax).
  float delta;      // Do Not Edit
  int8_t delta2;    // Sets forward or backwards direction amount. (Can be negative.)
  int palletPosition;
  int colorBarPosition;
  uint8_t loc1;
  int8_t advance;       // Stores the advance amount
  uint8_t colorStorage; // Stores a hue color.
  uint8_t count;
  uint16_t cycleLength; // Lover values = continuous flow, higher values = distinct pulses.
  uint16_t pulseLength; // How long the pulse takes to fade out.  Higher value is longer.
  uint16_t pulseOffset; // Delay before second pulse.  Higher value is more delay.
  float breath;
  uint8_t posR;
  uint8_t posG;
  uint8_t posB; // positions of moving R,G,B dots
  uint8_t pos;  // stores a position for color being blended in
  uint8_t hueA; // Start hue at valueMin.
  uint8_t satA; // Start saturation at valueMin.
  uint8_t hueB; // End hue at valueMax.
  uint8_t hue;  // Do Not Edit
  uint8_t hue2; // Do Not Edit
  uint8_t sat;  // Do Not Edit
  uint8_t satB; // End saturation at valueMax.
  float val;
  CRGB tempPatternCollection[MAX_LEDS];
  CRGB tempHalfLeds[MAX_LEDS / 2]; // half the total number of pixels
  CRGB leds[MAX_LEDS];
  CRGB tempLeds[MAX_LEDS];
  byte colorIndex[MAX_LEDS];
};
PatternSettings patternSettings = {
    .pattern = {},
    .patternAdjust = {},
    .favoritePattern = {},
    .favoritePatternAdjust = {},
    .favoriteMode = {},
    .numberOfFavorites = 25,
    .tempPattern = 0,
    .currentPattern = 0,
    .displayPattern = 0,
    .randomPattern = 0,
    .gHue = 0,
    .flowDirection = -1,
    .gReverseDirection = false,
    .sizeUpdate = 0,
    .moving = true,
    .speed = 0,
    .fadingTail = false,
    .fadeRate = 120,
    .valueMax = 255.0,
    .valueMin = 120.0,
    .delta = ((patternSettings.valueMax - patternSettings.valueMin) / 2.35040238),
    .delta2 = 170,
    .palletPosition = 1,
    .colorBarPosition = 0,
    .loc1 = 1,
    .advance = 0,
    .colorStorage = 0,
    .count = 0,
    .cycleLength = 0,
    .pulseLength = 1500,
    .pulseOffset = 150,
    .breath = 0,
    .posR = 0,
    .posG = 0,
    .posB = 0,
    .pos = 0,
    .hueA = 15,
    .satA = 230,
    .hueB = 95,
    .hue = patternSettings.hueA,
    .hue2 = patternSettings.hueB,
    .sat = patternSettings.satA,
    .satB = 255,
    .val = patternSettings.valueMin};

struct HSV2RGB
{
  int red, green, blue;    // used in hsv2rgb color functions
  int red2, green2, blue2; // used in hsv2rgb color functions
  int red3, green3, blue3; // used in hsv2rgb color functions
};
HSV2RGB globalHSV2RGB;

struct MenuModel
{
  int menu[36];
  int menuMax[36];
  int patternMax[MAX_MODES + 1];
  int currentMenu;
  int currentMenuMultiplier;
  u8g2_uint_t verticalDividePosition;
  u8g2_uint_t firstLineHorizontal;
  u8g2_uint_t secondLineHorizontal;
  u8g2_uint_t selectionBubblePadding;
  u8g2_uint_t selectionBubbleWidth;
  u8g2_uint_t selectionBubbleHeight;
  u8g2_uint_t selectionBubbleRadius;
};
MenuModel globalMenu = {
    .menu = {},
    //Root Menu Items, Game Menu Items, Settings Menu Items
    .menuMax = {
        3,                                 //Main
        5,                                 //Game
        7,                                 //Settings
        3,                                 //LED Settings
        1,                                 //ZIP Code
        3,                                 //Favorites Menu
        50,                                //Max Favorites
        1,                                 //Reset Favorites
        3,                                 //Wifi Menu
        3,                                 //Customize Menu
        patternSettings.numberOfFavorites, //Add Favorite
        99999,                             //Enter ZIP Code
        0,                                 //WiFi Scan Results (dynamically set)
        128,                               // WiFi Password
        3,                                 //WiFi Test
        (MAX_LEDS / 5),                    //# LEDs
        3,                                 //LED Color mode
        50,                                //LED SmoothOperator Fade Rate
        3,                                 //Speed?
        3,                                 //Time Menu
        6,                                 //Time Zone
        12,                                //Manual Time Entry Hour
        59,                                //Manual Time Entry Minute
        1,                                 //NTP
        7,                                 //Customize Display
        71,                                //Customize Timeout
        27,                                //Display 1
        27,                                //Display 2
        27,                                //Display 3
        71,                                //Random Timeout
        60,                                //Display 1 Duration
        60,                                //Display 2 Duration
        60,                                //Display 3 Duration
        10,                                //Display Brightness
        1,                                 //System Information
        60,                                //Power Limit
    },
    .patternMax = {
        patternSettings.numberOfFavorites, //Favorites (dynamic)
        23,                                //Basic Category
        7,                                 //Decor Category
        72,                                //Party Category
        18,                                //Advanced Category
        18,                                //Complex Category
        6,                                 //Special Category
        20,                                //Sound Reactive Category
        85,                                //Legacy
        20,                                //Weather Reactive Category
    },
    .currentMenu = 0,
    .currentMenuMultiplier = 1,
    .verticalDividePosition = 64,
    .firstLineHorizontal = 24,
    .secondLineHorizontal = 38,
    .selectionBubblePadding = 12,
    .selectionBubbleWidth = 64,
    .selectionBubbleHeight = 16,
    .selectionBubbleRadius = 7};
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
void loop()
{

  EVERY_N_MILLISECONDS(33) //Enforce Max Frame Rate 33 = 30FPS
  {
    if (coverInput == true)
    {
      updateEncoders();
    }
    globalStrings.functionName.toCharArray(globalStrings.functionNameOutString, 20);
    globalStrings.categoryName.toCharArray(globalStrings.categoryNameOutString, 20);

    //Clear the display buffer so we can draw new stuff
    u8g2.clearBuffer();

    switch (globals.runMode)
    {
    case 0: //Main run mode
      drawBottom();
      drawTop();
      showBrightnessDisplay();
      break;
    case 1: //Menu mode
      drawMenuCommander();
      break;
    case 2: //Game mode
      switch (globalMenu.menu[1])
      {
      case 0:
        fallios_game();
        break;
      case 1:
        blockbreaker_game();
        break;
      case 2:
        magic_game();
        break;
      case 3:
        snake_game();
        break;
      case 4:
        pong_game();
        break;
      case 5:
        snake2_game();
        break;
      }
      break;
    case 3: //Clock/Weather/Info modes
      displayTimer();
      showBrightnessDisplay();
      break;
    case -1:                           //Reset
      globalTime.touchTime = millis(); //Last touch time back to default
      globals.runMode = 0;             //Back to normal
      break;
    }

    //Show logo instead for first X millis
    showLogo(2500);

    //Clear active button clicks
    knob1.click = 0;
    knob2.click = 0;

    //Write buffer to display
    u8g2.sendBuffer();

    startBreathing();

    //Write current breath value to status LED
    ledcWrite(STATUS_LED, patternSettings.breath);

    patternSettings.displayPattern = patternSettings.pattern[globals.mode];

    if (patternSettings.displayPattern == 0)
    {
      if (((millis() - globals.randomTime) > globals.randomInterval) && globals.randomMin != 0)
      {
        pickRandom();
      }

      patternSettings.displayPattern = patternSettings.randomPattern;
    }

    globalStrings.functionName = "";

    switch (globals.mode)
    {
      case 0: // FAVORITES
        favorites_category(patternSettings.displayPattern);
        break;
      case 1: // BASIC
        basic_category(patternSettings.displayPattern);
        break;
      case 2: // DECOR
        decor_category(patternSettings.displayPattern);
        break;
      case 3: // PARTY
        moving_colors_category(patternSettings.displayPattern);
        break;
      case 4: // ADVANCED
        chill_category(patternSettings.displayPattern);
        break;
      case 5: // COMPLEX
        decor_category(patternSettings.displayPattern);
        break;
      case 6: // SPECIAL
        special_category(patternSettings.displayPattern);
        break;
      case 7: // SOUND REACTIVE
        soundReactive_category(patternSettings.displayPattern);
        break;
      case 8: // LEGACY
        legacy_category(patternSettings.displayPattern);
        break;
      case 9: // WEATHER REACTIVE
        weatherReactive_category(patternSettings.displayPattern);
        break;
    }

    //Detect mode changes and apply interfading
    smoothOperator();

    //Check to see if there are recent knob changes to store in memory
    saveTimeCheck();

    //Output data to LED strip
    FastLED.show();

    if (brightness.useFade == true)
    {
      brightness.current = brightness.current + brightness.fadeAmount;
      // reverse the direction of the fading at the ends of the fade:
      if (brightness.current == 0 || brightness.current == 255)
      {
        brightness.fadeAmount = -brightness.fadeAmount;
      }

      //delay(9); // This delay sets speed of the fade. I usually do from 5-75 but you can always go higher.
    }

    devEnv.fps++; //For tracking frame rate/ debug logging

    /*
  for (int i = 0; i < NUM_BANDS; i++)
  {
    int temp1 = 0;

    for (int ii = 0; ii < eqBands.averageSamples; ii++)
    {
      temp1 += eqBands.bandAverages[i][ii];
    }
    temp1 = temp1 / eqBands.averageSamples;

    //Debug Serial Logging
    Serial.print("Value[");
    Serial.print(i);
    Serial.print("]:");
    Serial.print(eqBands.bandValues[i]);
    Serial.print(", ");
    Serial.print("Average[");
    Serial.print(i);
    Serial.print("]:");
    Serial.print(temp1);
    Serial.print(", ");
  }
  Serial.println("");
  */

    // Serial.print(" ");
    // Serial.println(eqBands.bandValues[4]);
    //Serial.print(" ");

  // Serial.print(" ");
  // Serial.println(eqBands.bandValues[4]);
  //Serial.print(" ");

  /*
  EVERY_N_MILLISECONDS(10000)
  {
    Serial.print("FPS: ");
    Serial.println(devEnv.fps / 10);
    devEnv.fps = 0;
    Serial.print("IPS: ");
    Serial.println(devEnv.fftps / 10);
    devEnv.fftps = 0;
    //Serial.print("ICT: ");
    //Serial.println(eTaskGetState(inputComputeTask));
    Serial.print("MIN: ");
    Serial.println(((millis() / 1000) / 60));
  }
  */

  // slowly cycle the "base color" through the rainbow
  EVERY_N_MILLISECONDS(200) { patternSettings.gHue++; }

    autoConnect();
    //vTaskDelay(1);
  }
  //vTaskDelay(1);
}

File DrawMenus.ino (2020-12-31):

/*******************************************************************
 *  Menu System - globalMenu.currentMenu sets menu page. globalMenu.menu[] contains selection
 *                globalMenu.menuMax[] specifies max selection
 *  0 - Main Page
 *  1 - Games Page
 *  2 - Settings Page 
 *        3 - LED Count   4 - IP Address
 * 
 *  5 - Favorites Page
 *        6 - Max Favs    7 - Reset Favs   8 - New Fav 
 * *****************************************************************/

void drawMenu(int numberOfItems, int currentlySelected, ...)
{
  //Normal drawing color
  u8g2.setDrawColor(1);

  //Create a new list with however many items we received
  va_list menuItems;
  va_start (menuItems, currentlySelected);

  //Take the first string and send it to the drawMenuTop function
  drawMenuTop(String(va_arg (menuItems, char*)));

  //Spacers for top
  if (currentlySelected == 0)
  {
    u8g2.setCursor(4, 20);
    u8g2.print("- - - - - - -");
    u8g2.setCursor(4, 30);
    u8g2.print("- - - - - - -");
    for (int i = 1; i <= numberOfItems; i++)        
    {
      u8g2.setCursor(4, 30 + (10 * i));
      //u8g2.print(i);
      //u8g2.print(" - ");
      u8g2.print(String(va_arg (menuItems, char*))); 

      //Stop if we have gone off the screen
      if (i > 2)
      {
        i = 100;
      }
    }
  }

  if (currentlySelected == 1)
  {
    u8g2.setCursor(4, 20);
    u8g2.print("- - - - - - -");
    for (int i = 1; i <= numberOfItems; i++)        
    {
      u8g2.setCursor(4, 20 + (10 * i));
      //u8g2.print(i);
      //u8g2.print(" - ");
      u8g2.print(String(va_arg (menuItems, char*))); 

      //Stop if we have gone off the screen
      if (i > 3)
      {
        i = 100;
      }
    }
  }

  if (currentlySelected > 1)
  {
    //Cycle through offscreen items
    for (int i = 0; i <= currentlySelected - 3; i++)
    {
      String bogus = String(va_arg (menuItems, char*));
    }

    for (int i = 0; i <= numberOfItems - currentlySelected + 1; i++)        
    {
      u8g2.setCursor(4, 20 + (10 * i));
      //u8g2.print(i);
      //u8g2.print(" - ");
      u8g2.print(String(va_arg (menuItems, char*))); 

      //Stop if we have gone off the screen
      if (i >= 4)
      {
        i = 100;
      }
    }
  }

  //Spacers for bottom
  if (numberOfItems - currentlySelected == 2)
  {
    u8g2.setCursor(4, 60);
    u8g2.print("- - - - - - -");
  }

  if (numberOfItems - currentlySelected == 1)
  {
    u8g2.setCursor(4, 50);
    u8g2.print("- - - - - - -");
    u8g2.setCursor(4, 60);
    u8g2.print("- - - - - - -");
  }

  //Close our list
  va_end (menuItems);
  
  //Invert drawing color & draw the middle box
  u8g2.setDrawColor(2);
  u8g2.drawBox(0, 31, 128, 10);

  //Back to default draw color
  u8g2.setDrawColor(1);
}


void drawMenuWords(String menuName, String first, String second, String third, String fourth = "")
{
  drawMenuTop(menuName);

  u8g2.setCursor(5, globalMenu.firstLineHorizontal);
  u8g2.print(first);
  u8g2.setCursor(69, globalMenu.firstLineHorizontal);
  u8g2.print(second);
  u8g2.setCursor(5, globalMenu.secondLineHorizontal);
  u8g2.print(third);

  if (fourth == "")
  {
    u8g2.setCursor(69, globalMenu.secondLineHorizontal);
    u8g2.print("Back");
  }
  else
  {
    u8g2.setCursor(69, globalMenu.secondLineHorizontal);
    u8g2.print(fourth);
  }
  u8g2_horizontal_line(9);
}

void drawMenuCommander()
{
  u8g2.setFont(u8g2_font_ncenB08_tr);

    //Draw Screen
  switch (globalMenu.currentMenu)
  {
  case 0: // Draw Image
  {
    //drawMenuWords("Welican Gemina",
    //              "Games", "Settings", "Customize", "Exit");
    
    

    drawMenuSelectionFrames();

    if (globals.mode == 0)
    {
      drawMenuWords("Welican Gemina",
                    "Games", " - - - - - -", "Display", "Settings");
    }
    else
    {
      drawMenuWords("Welican Gemina",
                    "Games", "Favorite", "Display", "Settings");
    }
    

    drawIPAddress();
  }
  break;
  case 1: // Draw Games
  {
    drawMenu(6, globalMenu.menu[globalMenu.currentMenu], "Games", 
      "Fallios", "Block Breaker", "Magic 8 Ball", "Daddy Worm", "Pong", "2P - Daddy Worm");
  }
  break;
  case 2: // Draw Settings
  {
    //drawMenuWords("Settings",
    //              "LEDs", "Time", "ZIP Code", "WiFi");

    drawMenu(8, globalMenu.menu[globalMenu.currentMenu], "Settings",
      "LED Configuration", "Timezone", "Time (No Internet)", "ZIP Code", "WiFi","Max Favorites","Randomizer Time","System Information");
    //drawMenuSelectionFrames();
  }
  break;
  case 3: // LED
  {
    //drawMenuTop("Settings > LED Settings");
    //drawMenuWords("Settings > LED",
    //              "# LEDs", "Order", "Fade", "Speed");
    drawMenu(4, globalMenu.menu[globalMenu.currentMenu], "Settings > LED",
      "Number of LEDs", "Color Order", "Crossfade Amount", "Power Limit");

    //drawMenuSelectionFrames();
  }
  break;
  case 4: // Zip Code Menu
  {
    drawMenuTop("Settings > ZIP Code");

    u8g2.setCursor(16, 50);
    u8g2.print("Current ZIP Code ");

    updateZipCodeString();
    u8g2.print(weatherSettings.zipCode);
  }
  break;
  case 5:
  {

  }
  break;
  case 6: //Max Favorites
  {
    drawNumberInput("Settings > Max Favorites",
                    globalMenu.menu[globalMenu.currentMenu]);

    if (globalMenu.menu[globalMenu.currentMenu] < 1) //gotta have at least 1 favorite
    {
      globalMenu.menu[globalMenu.currentMenu] = 1;
    }
  }
  break;
  case 7: // Favorites Reset Menu
  {
    drawYesNoMenuFrame("Factory Reset?");
  }
  break;
  case 8: // WIFI Menu
  {
    switch (globals.softAPEnable)
    {
    case 0:
    {
      drawMenuWords("Settings > WiFi",
                    "Scan", "Host", "Connect", "Disconn.");
    }
    break;

    case 1:
    {
      drawMenuWords("Settings > WiFi",
                    "Scan", "Hosting!", "Connect", "Disconn.");
    }
    break;
    }
    drawMenuWords("Settings > WiFi",
                  "Scan", "Host", "Connect", "Disconn.");

    u8g2.setCursor(10, 64);
    drawIPAddress();
    if (WiFi.status() == WL_CONNECTED)
    {     
      int temp = WiFi.SSID().length();
      temp = 64 - (temp * 2);

      if (temp < 0)
      {
        temp = 0;
      }

      u8g2.setCursor(temp, 51);
      u8g2.print(WiFi.SSID());

      //u8g2.print("   ");
      //u8g2.print(RSSItoPercent(WiFi.RSSI()));
      //u8g2.print(WiFi.RSSI());
      //u8g2.print("%");

    }
    drawMenuSelectionFrames();
  }
  break;
  case 9:
  {

  }
  break;
  case 10: // Add New Favorites Menu
  {
    newFavoritesMenu();
  }
  break;
  case 11: // Set Zip Code Menu
  {
    setZipCodeMenu();
  }
  break;
  case 12: // WIFI Scan Results
  {
    drawMenuTop("WiFi Scan Results");

    u8g2.setCursor(15, 60);
    if (globals.networkScan == WIFI_SCAN_FAILED)
    {
      u8g2.print("Scan Failed");
    }

    if (globals.networkScan == 0)
    {
      Serial.println("No Networks Found");
    }
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

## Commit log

2020-08-31 Breathing LED status indicator on Gemina boards
2020-09-02 readme and merge fixes
    [Welican_Gemina.ino]
2020-09-02 added npm, webpack, and better framework for website dev
2020-09-03 added new website framework, uses NPM, Bulma CSS, and webpack to give a decent starting point for a website
2020-09-04 Replaced encoder Library with ESP32Encoder
    [Utils.ino, Welican_Gemina.ino]
2020-09-06 fixed build errors aroudn sawtooth and plasma
    [MovingColorsCategory.ino, Utils.ino, Welican_Gemina.ino]
2020-09-07 added rainbow flow, rainbow hsv, color flow bounch, dual color flow bounce, dual color flow, and maybe more
2020-09-14 Implemented FFT to replace MSGEQ7 (#15)
    [DrawBottoms.ino, Utils.ino, Welican_Gemina.ino]
2020-09-16 Added board designs
    [ESP32-Proto2-LayoutA.brd, ESP32-Proto2-LayoutA.sch, Rotary_Alps_B.brd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]
2020-09-18 Bug fixes and multicore optimizations
    [Utils.ino, Welican_Gemina.ino]
2020-09-22 Bug fixes and a new game type
    [Utils.ino, Welican_Gemina.ino]
2020-09-22 OSH Park designs from round 2
    [ESP32-Proto2-OSHPARK.brd, ESP32-Proto2-OSHPARK.sch, Rotary_Alps_C.brd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]
2020-09-28 Small fixes for network time & favorites
    [DrawBottoms.ino, Utils.ino, Welican_Gemina.ino]
2020-09-29 Timezone and DST fixes
    [DrawBottoms.ino, Utils.ino, Welican_Gemina.ino]
2020-09-30 removed broken httpclient code
    [Welican_Gemina.ino]
2020-09-30 fixed serial print for weather
    [Utils.ino]
2020-09-30 fixed open weather object
    [Utils.ino, Welican_Gemina.ino]
2020-10-01 added current menu to globals
2020-10-01 fixed build errors around global time
    [MovingColorsCategory.ino, Utils.ino, Welican_Gemina.ino]
2020-10-01 fixed errors and made more defines for LED count
    [Utils.ino, Welican_Gemina.ino]
2020-10-01 added fade direction to globa led
2020-10-02 cleaning up more variables, simplex noise
    [LegacyCategory.ino, MovingColorsCategory.ino, Utils.ino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]
2020-10-02 adding more variables to simplex noise
    [ChillCategory.ino, LegacyCategory.ino, Utils.ino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]
2020-10-02 added more to simplex noise
    [Utils.ino, Welican_Gemina.ino]
2020-10-08 fixed spacing of game name
    [MagicGame.ino]
2020-10-08 fixed some spacing on magic game
    [MagicGame.ino]
2020-10-08 Favorites fix and random improvements
    [BasicCategory.ino, ChillCategory.ino, DrawHelpers.ino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]
2020-10-09 Randomizer fixes, works as a favorite now
    [DrawHelpers.ino, Utils.ino]
2020-10-10 Set/Store/Recall Number of LEDs
2020-10-16 Fixed some bugs with display types and saving
    [LightHelpers.ino, Utils.ino]
2020-10-16 timerd delay
2020-10-18 Fixed Midnight showing as 0 for Clocks
    [DrawHelpers.ino, DrawMenus.ino, Welican_Gemina.ino]
2020-10-18 fixed case statement
2020-10-24 New miniature board layout
    [ESP32-Mini1-OSHPARK.sch]
2020-10-26 Cleaning up Update Encoder code
2020-10-28 Board stencils w/ drill sizes
2020-11-03 Increased i2c frequency for higher frame rate
2020-11-16 New board designs
    [5V-DCDC.brd, 5V-DCDC.sch, ESP32-Mini1-B.brd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]
2020-11-20 Better snake collision checking
    [SnakeGame.ino]
2020-11-29 Fixed favorite saving glitch
    [DrawHelpers.ino, SnakeGame.ino, Welican_Gemina.ino]
2020-12-04 Fixed sunrise and sunset times
    [Utils.ino]
2020-12-07 working on getting current and daily open call APIs
2020-12-07 got all 7 days + current day parsing from daily weather api call
2020-12-07 added better logging for open weather and fixed some parsing
    [Utils.ino]
2020-12-12 Multiple displays with unique timers, LED status
2020-12-13 LED Blink when adding new favorite
2020-12-13 added timerDelay to user
2020-12-14 got all categories working, but legacy is broken?
    [DrawHelpers.ino, WebsiteHelper.ino, Welican_Gemina.ino]
2020-12-14 removed Legacy_Category, kept freezing system. Whooops? Dunno how it happened. But I did make it so we have 9 category slots available. So LET'S EXPAND!
2020-12-14 fixed if user exists check
    [FirebaseHelper.ino]
2020-12-14 got user saving correctly and scores updating after a game ends
    [FalliosGame.ino, FirebaseHelper.ino, Utils.ino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]
2020-12-14 Fixed glitch with Legacy category
    [LegacyCategory.ino, LightHelpers.ino, Utils.ino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]
2020-12-14 fixed logic for updating user data
    [Utils.ino]
2020-12-14 fixed build errors again
    [BlockBreakerGame.ino]
2020-12-14 fixed more build errors
    [BlockBreakerGame.ino, Utils.ino]
2020-12-14 fixed path to user data
    [Utils.ino]
2020-12-15 added VUE js project for highscore website framework
2020-12-17 adding in basic high score website
    [5V-DCDC.brd, 5V-DCDC.sch, ESP32-Mini1-B.brd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]
2020-12-17 fixed name of score for daddy worm
    [FirebaseHelper.ino]
2020-12-17 removed save button on modal
2020-12-17 added back in boards folder
    [5V-DCDC.brd, 5V-DCDC.sch, ESP32-Mini1-B.brd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]
2020-12-17 added back Boards and data folder to correct place
    [5V-DCDC.brd, 5V-DCDC.sch, ESP32-Mini1-B.brd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]
2020-12-18 added Welican board images and got highscores website deployed
2020-12-20 fixed placement of degree marks on weather display
    [DrawHelpers.ino]
2020-12-20 Spelling error fix, small changes
    [DrawHelpers.ino, DrawMenus.ino, Welican_Gemina.ino]
2020-12-23 More responsive buttons/encoders
2020-12-27 Power limit menu
2020-12-29 Fixed bug when creating new favorite
    [Utils.ino]
2020-12-30 Fixed power menu glitch
    [DrawMenus.ino]
2020-12-30 Fixed small glitch for Display Brightness settings
    [DrawMenus.ino]
2020-12-30 Hold both buttons to exit, small glitch fixed
    [PongGame.ino]

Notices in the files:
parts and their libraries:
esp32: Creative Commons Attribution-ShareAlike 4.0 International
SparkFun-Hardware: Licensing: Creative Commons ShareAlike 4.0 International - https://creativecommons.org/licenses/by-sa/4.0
